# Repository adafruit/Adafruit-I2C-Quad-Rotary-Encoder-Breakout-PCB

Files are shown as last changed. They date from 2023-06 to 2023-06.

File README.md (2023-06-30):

## Adafruit I2C Quad Rotary Encoder Breakout with NeoPixel - STEMMA QT / Qwiic PCB

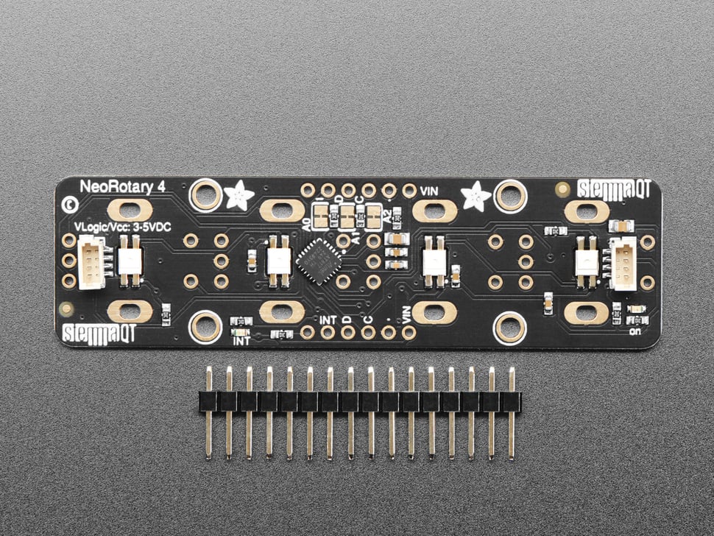
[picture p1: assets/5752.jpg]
<a href="http://www.adafruit.com/products/5752"><br/>
Click here to purchase one from the Adafruit shop</a>

PCB files for the Adafruit I2C Quad Rotary Encoder Breakout with NeoPixel - STEMMA QT / Qwiic. 

Format is EagleCAD schematic and board layout
* https://www.adafruit.com/product/5752

### Description

Rotary encoders are soooo much fun! Twist em this way, then twist them that way. Unlike potentiometers, they go all the way around and often have little detents for tactile feedback. But, if you've ever tried to add encoders to your project you know that they're a real challenge to use: timers, interrupts, debouncing...

This Stemma QT breakout makes all that frustration go away - and allows you to read up to 4 encoders for big builds with lots of twisty interfaces. You can solder in any four 'standard' PEC11-pinout rotary encoders with or without a push-switch. The onboard microcontroller is programmed with our seesaw firmware and will track all pulses and pins for you and then save the incremental value for querying at any time over I2C. Plug it in with a Stemma QT cable for instant rotary goodness, with any kind of microcontroller from an Arduino UNO up to a Raspberry Pi.

You can use our Arduino library to control and read data with any compatible microcontroller. We also have CircuitPython/Python code for use with computers or single-board Linux boards.

It's also easy to add this breakout to a breadboard - with six 0.1"-spaced breakout pads. Power with 3 to 5V DC and then use 3 or 5V logic I2C data. The INT pin can be configured to pulse low whenever rotation or push-buttoning is detected so you do not have to spam-read the I2C port to detect motion.

If you happen to be using clear/translucent shaft encoders, there are reverse-mount NeoPixels on board, that can display any color you like, they are controlled over I2C for additional visual feedback or keep them off if you like. Note that for metal-shaft encoders, the LEDs are not visible. On the back, there's a green power LED as well as a red INT LED that, if the interrupt is configured, will blink when the interrupt fires.

Using the three onboard address jumpers, you can connect up to 8 of these encoders on a single I2C port. The first one will be at address 0x49, the last one at 0x51 when all three jumpers are cut open.

To get you going fast, we spun up a custom-made PCB with the seesaw chip and all supporting circuitry, in the STEMMA QT form factor, making them easy to interface with. The STEMMA QT connectors on either side are compatible with the SparkFun Qwiic I2C connectors. This allows you to make solderless connections between your development board and the rotary encoder or to chain them with a wide range of other sensors and accessories using a compatible cable. QT Cable is not included, but we have a variety in the shop.

This breakout does not come with any encoders soldered on, so you can pick whatever encoder you like. We sell a common 24-detent-with-switch encoder here and it works wonderfully. You can also use encoders without detents or with a different number of detents per rotation, of course! You'll need to solder the encoders and optional header onto the PCB to use with a solderless breadboard. but it's fairly easy and takes only a few minutes even for a beginner.

### License

Adafruit invests time and resources providing this open source design, please support Adafruit and open-source hardware by purchasing products from [Adafruit](https://www.adafruit.com)!

Designed by Limor Fried/Ladyada for Adafruit Industries.

Creative Commons Attribution/Share-Alike, all text above must be included in any redistribution. 
See license.txt for additional details.

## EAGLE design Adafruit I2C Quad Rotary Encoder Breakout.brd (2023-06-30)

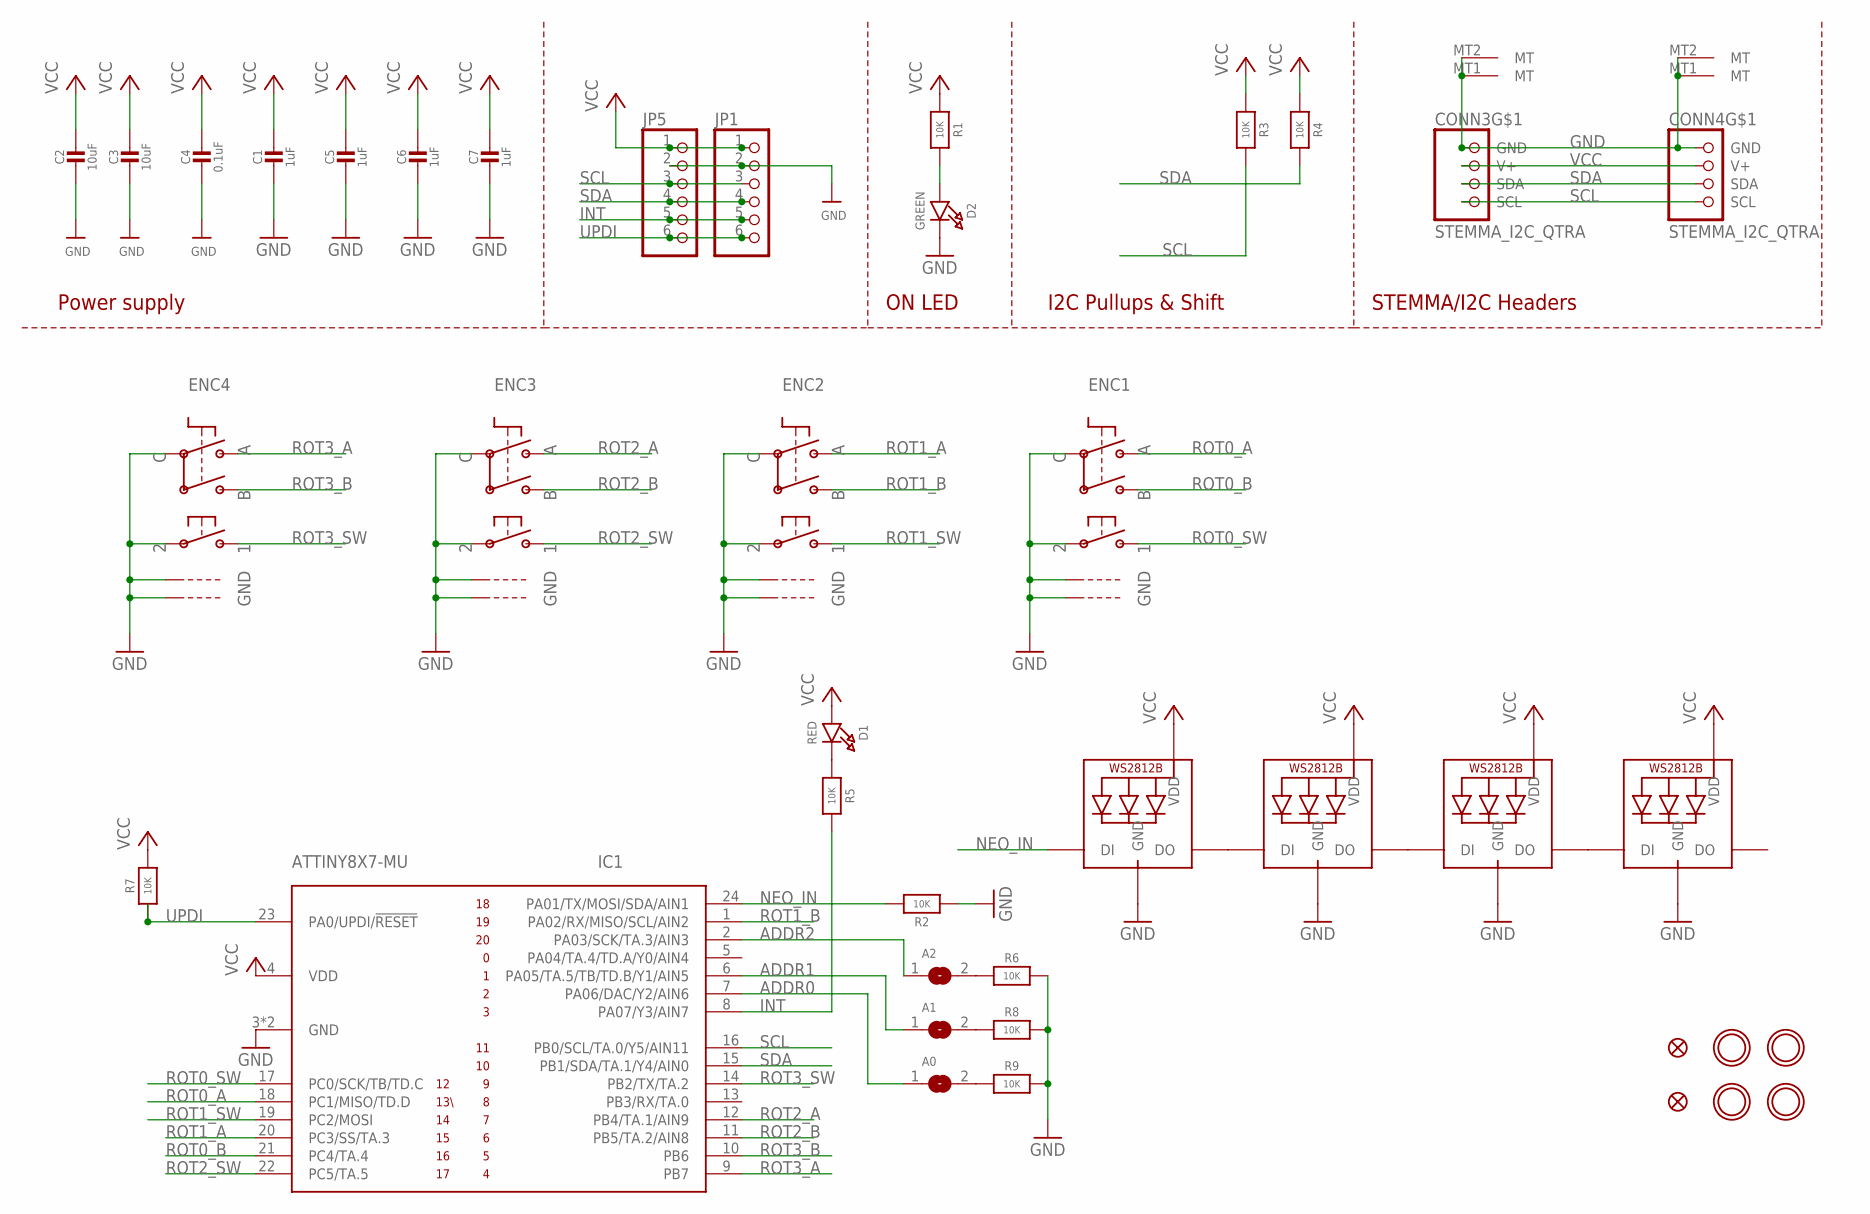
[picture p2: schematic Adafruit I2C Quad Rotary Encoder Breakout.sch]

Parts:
A0, A1, A2: SOLDERJUMPERCLOSED; SOLDERJUMPER_CLOSEDWIRE
C1, C5, C6, C7: 1uF; 0603-NO
C2, C3: 10uF; 0805-NO
C4: 0.1uF; 0603-NO
CONN3, CONN4: STEMMA_I2C_QTRA; JST_SH4_RA
D1: RED; CHIPLED_0603_NOOUTLINE
D2: GREEN; CHIPLED_0603_NOOUTLINE
ENC1, ENC2, ENC3, ENC4: ENCODER_PLUS_SWITCH_BOURNS_PEC11; PEC11+SWITCH
FID1, FID2: FIDUCIAL_1MM
IC1: ATTINY8X7-MU; QFN24_4MM
JP1, JP5: HEADER-1X670MIL; 1X06_ROUND_70
LED1, LED2, LED3, LED4: WS2812B_SK6812E; NEO3535_REVERSE
R1, R2, R3, R4, R5, R6, R7, R8, R9: 10K; 0603-NO
U$3, U$17, U$19, U$21: MOUNTINGHOLE2.5; MOUNTINGHOLE_2.5_PLATED

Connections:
ADDR0: A0.1, IC1.7 (PA06/DAC/Y2/AIN6)
ADDR1: A1.1, IC1.6 (PA05/TA.5/TB/TD.B/Y1/AIN5)
ADDR2: A2.1, IC1.2 (PA03/SCK/TA.3/AIN3)
GND: C1.2, C2.2, C3.2, C4.2, C5.2, C6.2, C7.2, CONN3.1 (GND), CONN3.MT1 (MT), CONN3.MT2 (MT), CONN4.1 (GND), CONN4.MT1 (MT), CONN4.MT2 (MT), D2.C, ENC1.P$2, ENC1.P$C, ENC1.P$GND1, ENC1.P$GND2, ENC2.P$2, ENC2.P$C, ENC2.P$GND1, ENC2.P$GND2, ENC3.P$2, ENC3.P$C, ENC3.P$GND1, ENC3.P$GND2, ENC4.P$2, ENC4.P$C, ENC4.P$GND1, ENC4.P$GND2, IC1.3 (GND), IC1.THERM (GND), JP1.2, JP5.2, LED1.3-GND (GND), LED2.3-GND (GND), LED3.3-GND (GND), LED4.3-GND (GND), R2.1, R6.2, R8.2, R9.2
INT: IC1.8 (PA07/Y3/AIN7), JP1.5, JP5.5, R5.2
unnamed: D2.A, R1.2
unnamed: LED1.2-DOUT (DO), LED2.4-DIN (DI)
unnamed: LED2.2-DOUT (DO), LED3.4-DIN (DI)
unnamed: LED3.2-DOUT (DO), LED4.4-DIN (DI)
unnamed: D1.C, R5.1
unnamed: A2.2, R6.1
unnamed: A1.2, R8.1
unnamed: A0.2, R9.1
NEO_IN: IC1.24 (PA01/TX/MOSI/SDA/AIN1), LED1.4-DIN (DI), R2.2
ROT0_A: ENC1.P$A, IC1.18 (PC1/MISO/TD.D)
ROT0_B: ENC1.P$B, IC1.21 (PC4/TA.4)
ROT0_SW: ENC1.P$1, IC1.17 (PC0/SCK/TB/TD.C)
ROT1_A: ENC2.P$A, IC1.20 (PC3/SS/TA.3)
ROT1_B: ENC2.P$B, IC1.1 (PA02/RX/MISO/SCL/AIN2)
ROT1_SW: ENC2.P$1, IC1.19 (PC2/MOSI)
ROT2_A: ENC3.P$A, IC1.12 (PB4/TA.1/AIN9)
ROT2_B: ENC3.P$B, IC1.11 (PB5/TA.2/AIN8)
ROT2_SW: ENC3.P$1, IC1.22 (PC5/TA.5)
ROT3_A: ENC4.P$A, IC1.9 (PB7)
ROT3_B: ENC4.P$B, IC1.10 (PB6)
ROT3_SW: ENC4.P$1, IC1.14 (PB2/TX/TA.2)
SCL: CONN3.4 (SCL), CONN4.4 (SCL), IC1.16 (PB0/SCL/TA.0/Y5/AIN11), JP1.3, JP5.3, R3.2
SDA: CONN3.3 (SDA), CONN4.3 (SDA), IC1.15 (PB1/SDA/TA.1/Y4/AIN0), JP1.4, JP5.4, R4.2
UPDI: IC1.23 (PA0/UPDI/!RESET), JP1.6, JP5.6, R7.1
VCC: C1.1, C2.1, C3.1, C4.1, C5.1, C6.1, C7.1, CONN3.2 (V+), CONN4.2 (V+), D1.A, IC1.4 (VDD), JP1.1, JP5.1, LED1.1-VDD (VDD), LED2.1-VDD (VDD), LED3.1-VDD (VDD), LED4.1-VDD (VDD), R1.1, R3.1, R4.1, R7.2

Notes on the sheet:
I2C Pullups & Shift
STEMMA/I2C Headers
ON LED
Power supply

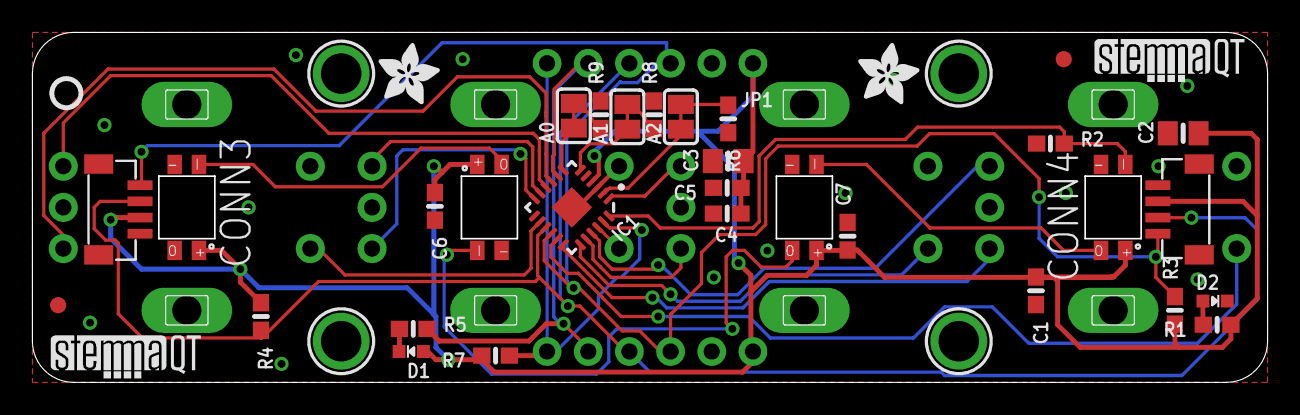
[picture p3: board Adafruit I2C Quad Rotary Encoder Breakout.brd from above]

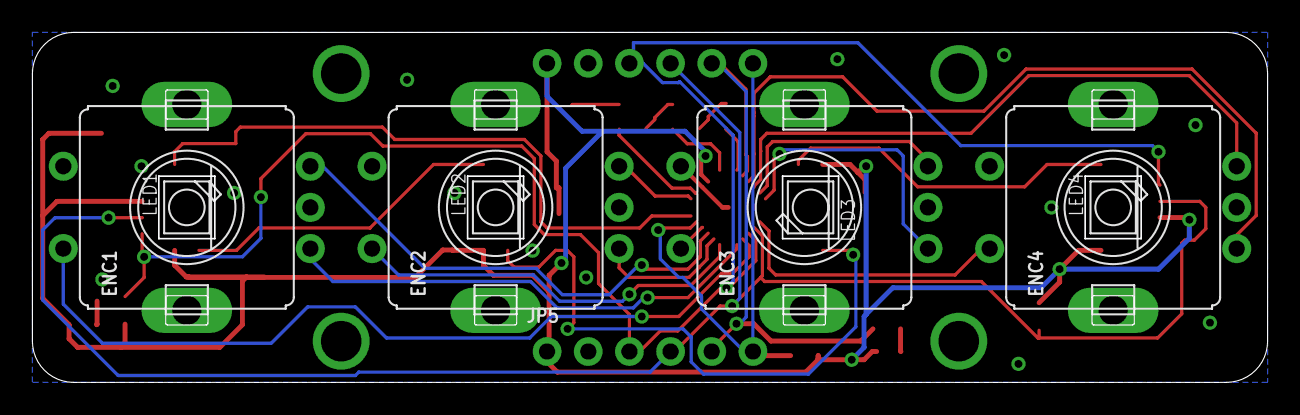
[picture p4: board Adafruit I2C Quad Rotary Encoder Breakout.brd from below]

Board: 2 copper layers, 76.2 x 21.6 mm, 78 parts (25 on the bottom side), 30 nets.

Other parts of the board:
PLABEL0: PLABEL0
PLABEL1: PLABEL1
PLABEL2: PLABEL2
PLABEL3: PLABEL3
PLABEL4: PLABEL4
PLABEL5: PLABEL5
PLABEL6: PLABEL6
PLABEL7: PLABEL7
PLABEL8: PLABEL8
PLABEL9: PLABEL9
PLABEL10: PLABEL10
PLABEL11: PLABEL11
PLABEL12: PLABEL12
PLABEL13: PLABEL13
PLABEL14: PLABEL14
PLABEL15: PLABEL15
PLABEL16: PLABEL16
PLABEL17: PLABEL17
PLABEL18: PLABEL18
PLABEL19: PLABEL19
PLABEL20: PLABEL20
PLABEL21: PLABEL21
PLABEL22: PLABEL22
PLABEL23: PLABEL23
PLABEL24: PLABEL24
PLABEL25: PLABEL25
PLABEL26: PLABEL26
PLABEL27: PLABEL27
PLABEL28: PLABEL28
PLABEL29: PLABEL29
PLABEL30: PLABEL30
PLABEL31: PLABEL31
PLABEL32: PLABEL32
U$2, U$9: ADAFRUIT_3.5MM
U$25: PCBFEAT-REV-040
U$30, U$31: STEMMAQT

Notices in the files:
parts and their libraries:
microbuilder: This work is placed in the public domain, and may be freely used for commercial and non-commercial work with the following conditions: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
